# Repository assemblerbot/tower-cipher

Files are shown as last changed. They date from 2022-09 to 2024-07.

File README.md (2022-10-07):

# The Tower cipher
Mechanical 3D printable cipher device for **education and hobby purposes** only.
It's based on the similar principle as most rotor cipers.
The Tower cipher uses **5mm metalic (or glass) ball** as a signal carrier to trace letters through pseudo-random pathways inside rotors.

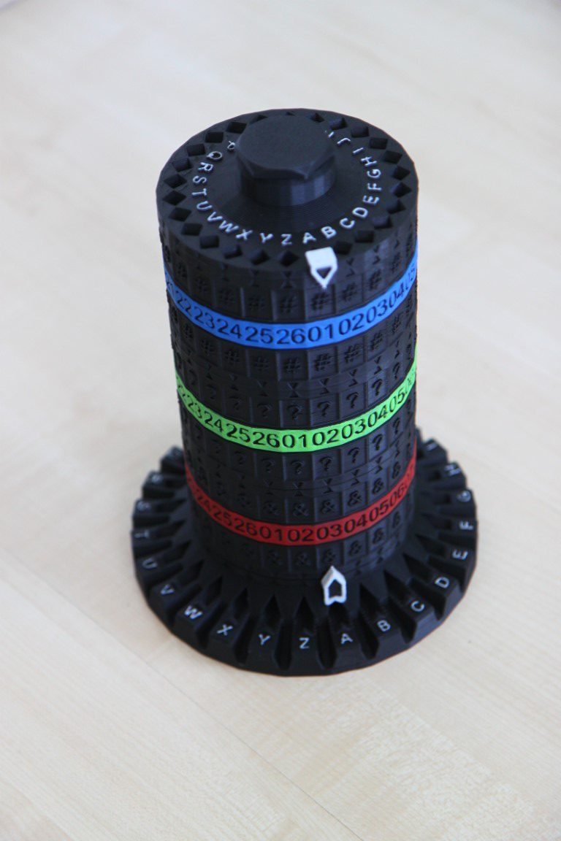
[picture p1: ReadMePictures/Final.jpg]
Final version


## Folders
[STL](https://github.com/assemblerbot/tower-cipher/tree/main/STL) contains printable files and assembly instructions.
In the [Model](https://github.com/assemblerbot/tower-cipher/tree/main/Model) folder there is a Blender source file for the whole device.
[Tools/Pathways generator](https://github.com/assemblerbot/tower-cipher/tree/main/Tools/PathwaysGenerator) is the tool I've created for generating internal pathways.

## Operation
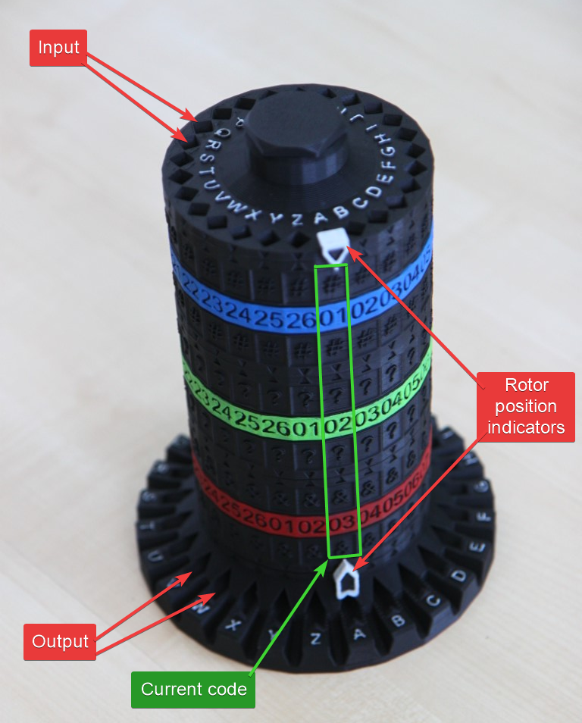
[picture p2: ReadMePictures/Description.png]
Description


### Video
[YouTube - how to use Tower cipher](https://youtu.be/TXNiqYJ8YBw)

### Printable sites
[Tower cipher on Printables](https://www.printables.com/model/290571-tower-cipher)

### Key
Secret phrase or the key consists of 2 mandatory parts and one optional part:
- order of rotors
- rotor settings
- optional - rotation pattern

Consider following example of the key (also on the picture above):
```
#01 ?02+1 &03
```

In this case:
- order of rotors from top to bottom in case of encryption and from bottom to top in case of decryption is `#?&`
- rotor `#` must be set to position `01`
- rotor `?` must be set to position `02`
- rotor `&` must be set to position `03`

There is also an optional rotation pattern: after each letter the position on the rotor `?` should be increased by `+1`.

### Encryption
1. Setup the device. Order of rotors is by the key **from top to bottom**.
2. Throw the ball to the letter hole on the top for next letter of a plaintext.
3. Ball returnes from one of bottom holes and indicates the letter from ciphertext.
4. Turn rotors by rotation pattern.
5. Repeat from step 2.

### Decryption
1. Setup the device. Order of rotors is inverted **from bottom to top**.
2. Throw the ball to the letter hole on the top for each ciphertext.
3. Ball returnes from one of bottom holes and indicates the letter from plaintext.
4. Turn rotors by rotation pattern.
5. Repeat from step 2.

## Additional features
There is a small ball storage on the top.
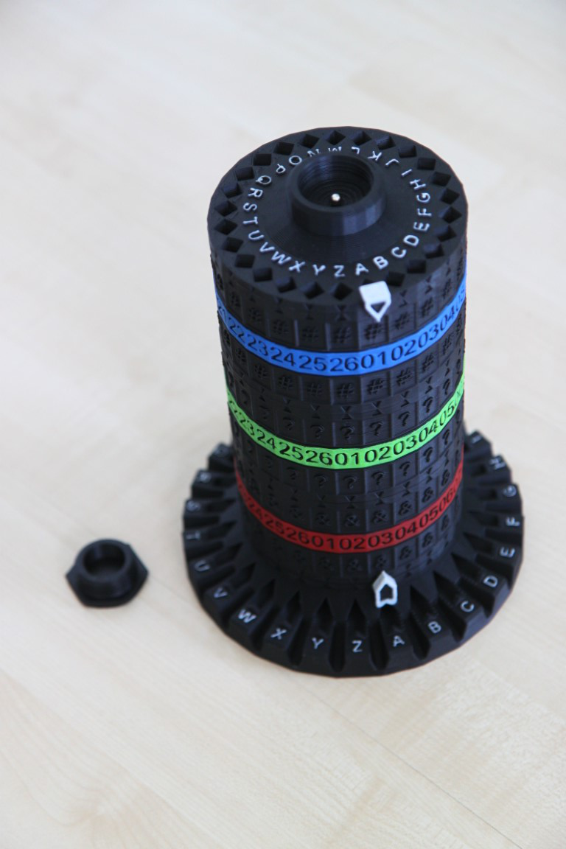
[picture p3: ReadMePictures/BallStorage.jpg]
Ball storage


Tweezers can be stored in a storage are at the bottom of the base part.
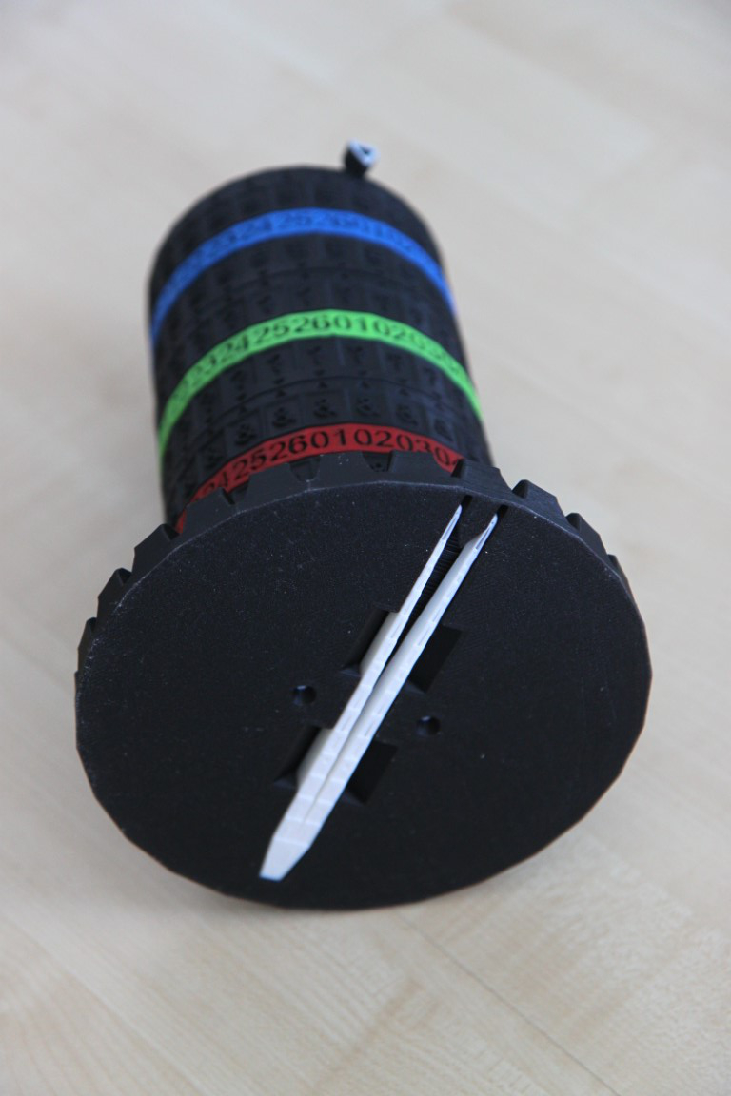
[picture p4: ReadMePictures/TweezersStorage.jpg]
Tweezers storage


## Notes

### Rotation pattern
Rotation pattern is optional.
If it's missing the device works as simple substitution cipher susceptible to frequency analysis.

### Internal rotor structure
Published version of Tower cipher uses 3 layers per each rotor where pin connections occur (see the Pathways generator for details).
Therefore randomness of connections is limited and is not entirely random.

Also straight connections (A to A) and short connections between neighbouring pins are not implemented.

### Key strength
Since the internal structure of the device is known, there are `3*2*1` combinations of rotor placements and `26*26*26` combinations of rotor positions which yields `105456` combinations the key without rotation patterns.
Rotation pattern can significantly increase the encryption strength yet too complex patterns might be hard to use.

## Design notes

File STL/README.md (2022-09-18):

# Tower cipher printing

## Prerequisites
You will need:
- 1 kg of filament (a bit less, but it depends on your slicer settings)
- 5mm metal or glass ball

## Slicing
I recommend following settings for Prusa slicer but of course you know your printer and what works for it the best.
Standard PLA, nozzle diameter 0.6mm, layer height 0.35, no supports are needed.

### Axle
This part should be strong.
- 3 perimeters
- 15% gyroid infill
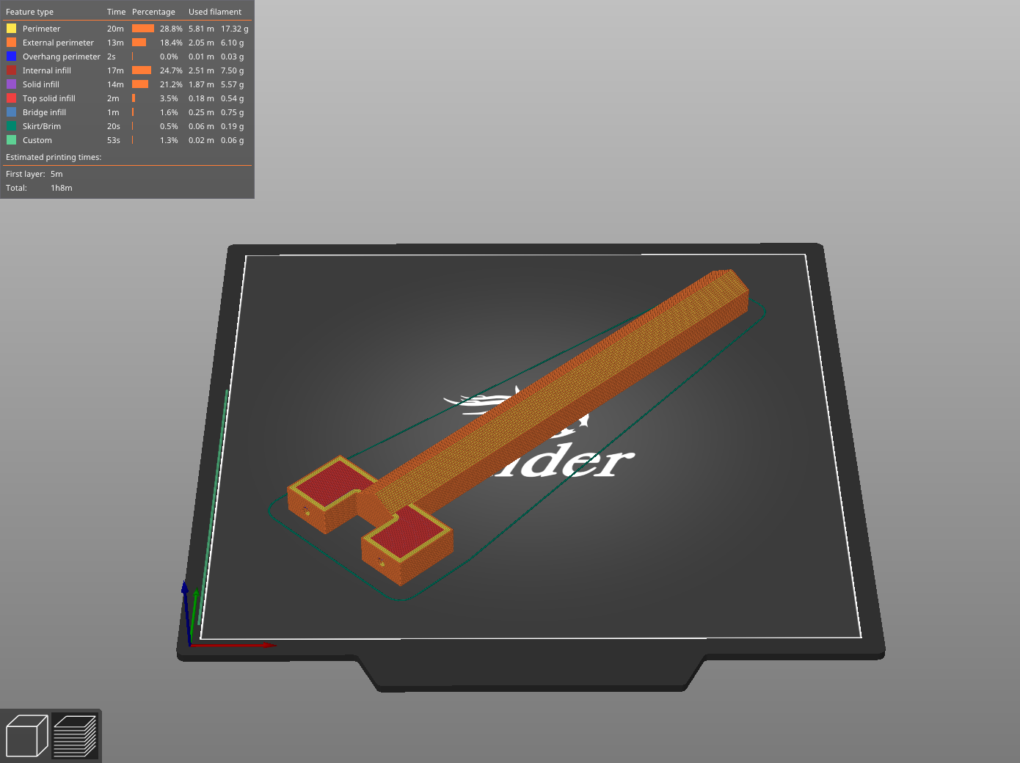
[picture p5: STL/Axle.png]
Axle


### Base, Top and Bolt
Nothing special, I've used:
- 2 perimeters
- 10% infill
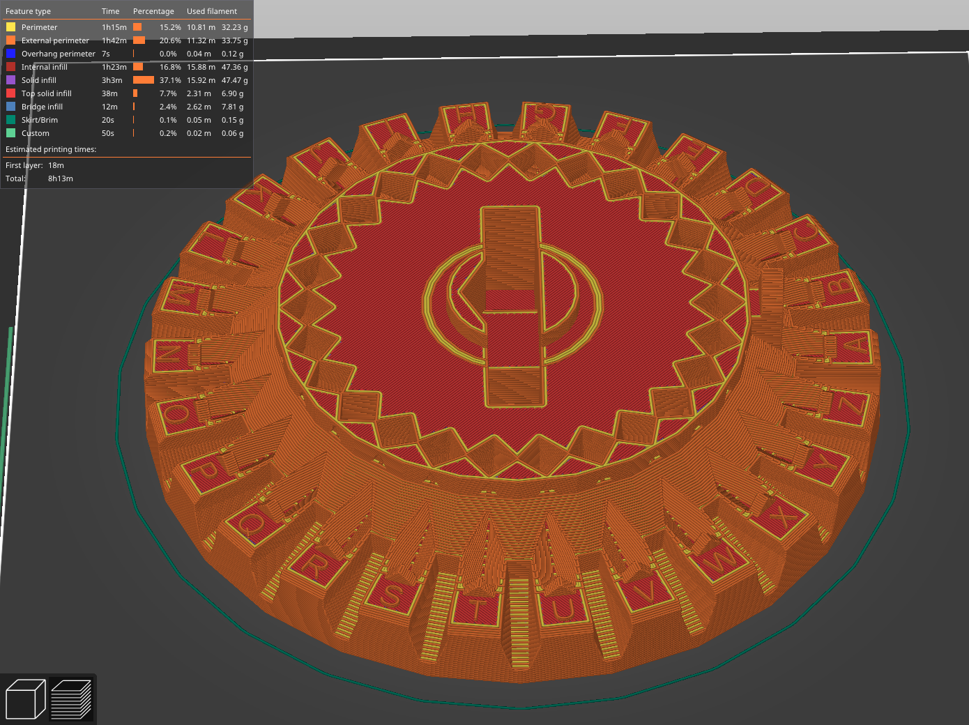
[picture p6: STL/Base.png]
Base


### Break
**Print it 3x** and with following parameters:
- 2 perimeters
- 15% infill
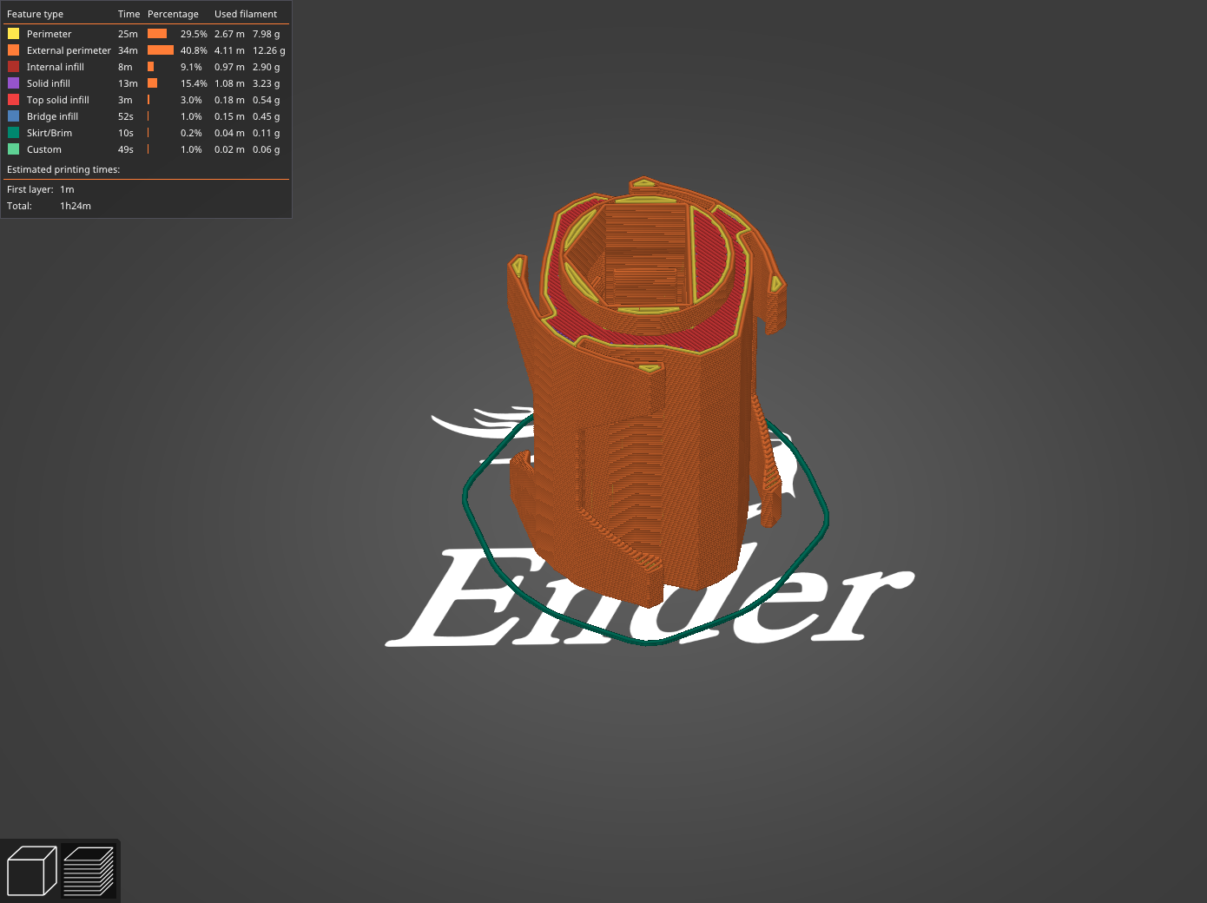
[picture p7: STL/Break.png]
Break


### Rotors
The tricky part. Can be printed on Enter 3 with default speeds under 10 hours with following settings:
- 2 perimeters
- **10% rectilinear infill**
- add range modifier between heights 1mm - 57mm and set *Bottom solid layers* and *Top solid layers* to 0
  - this setting significantly reduce printing time while that infill supports pathways nicely
- Solid infill threshold area: 0
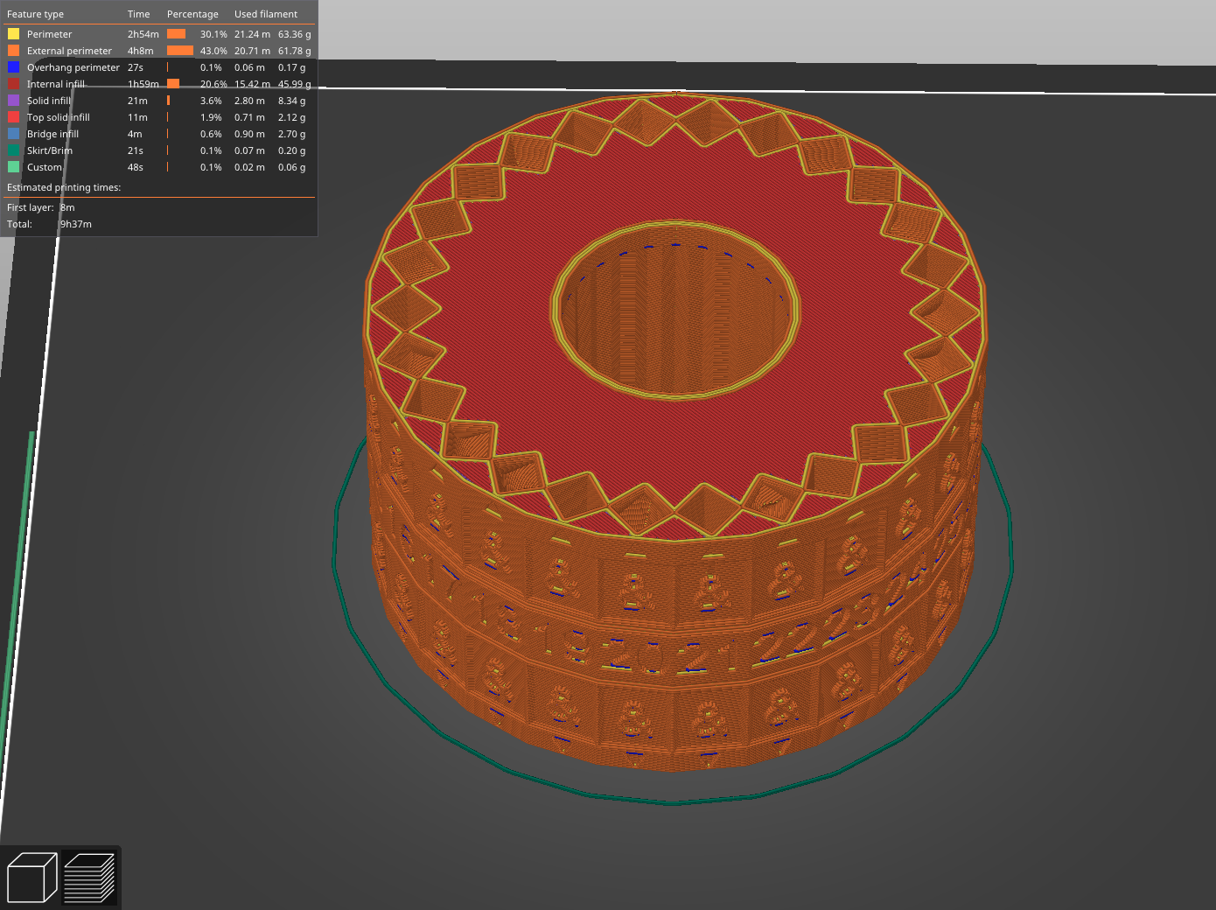
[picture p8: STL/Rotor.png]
Rotor


There is no need for solid infill inside the rotor.
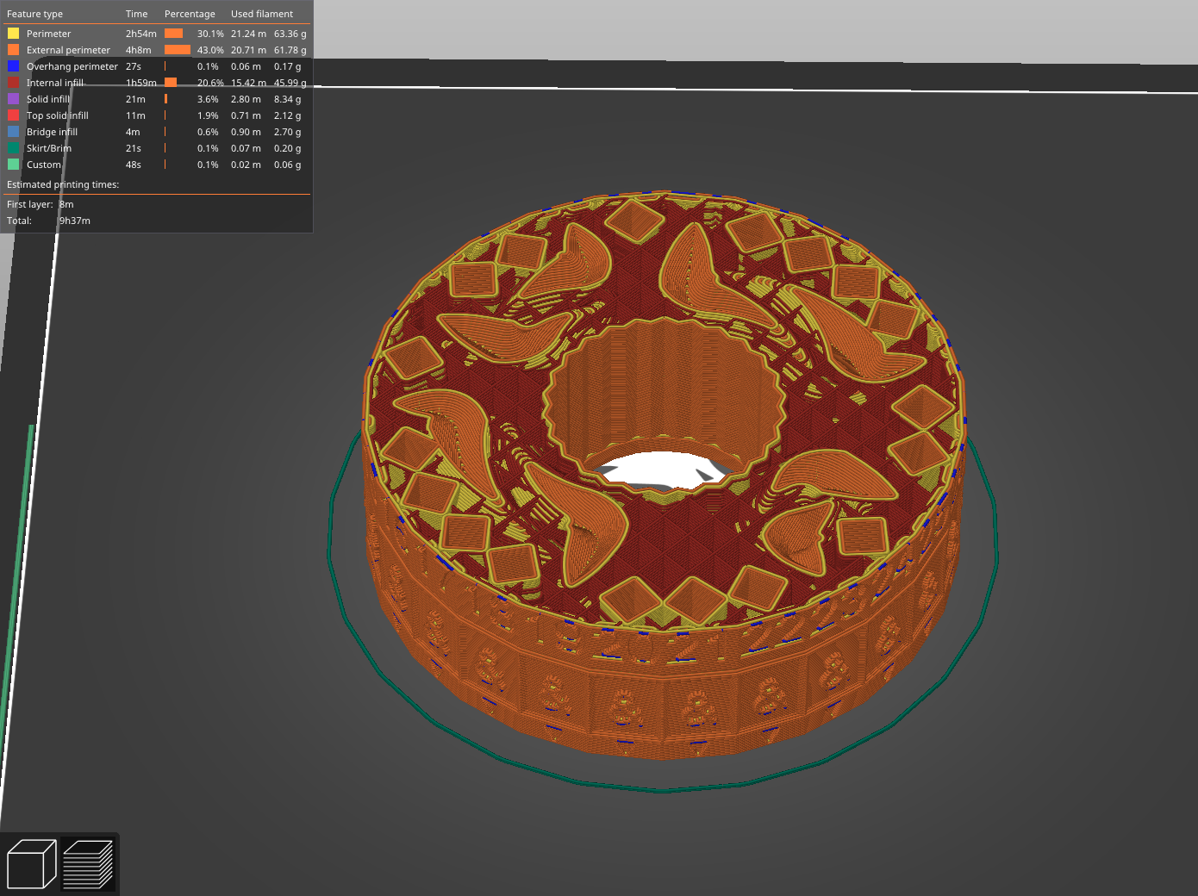
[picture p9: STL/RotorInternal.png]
RotorInternalStructure


### Tweezers
Tweezers can be a bit problematic if you have warping issues.
- 4 perimeters
- 15% infill (almost doesn't matter)
- I've turned off "Fill gaps" - that helped with warping because extruder is not returning back to fill in those tiny holes
- Classic perimeter generator instead of Arachne

## Printing
When your print is done you should have these parts.
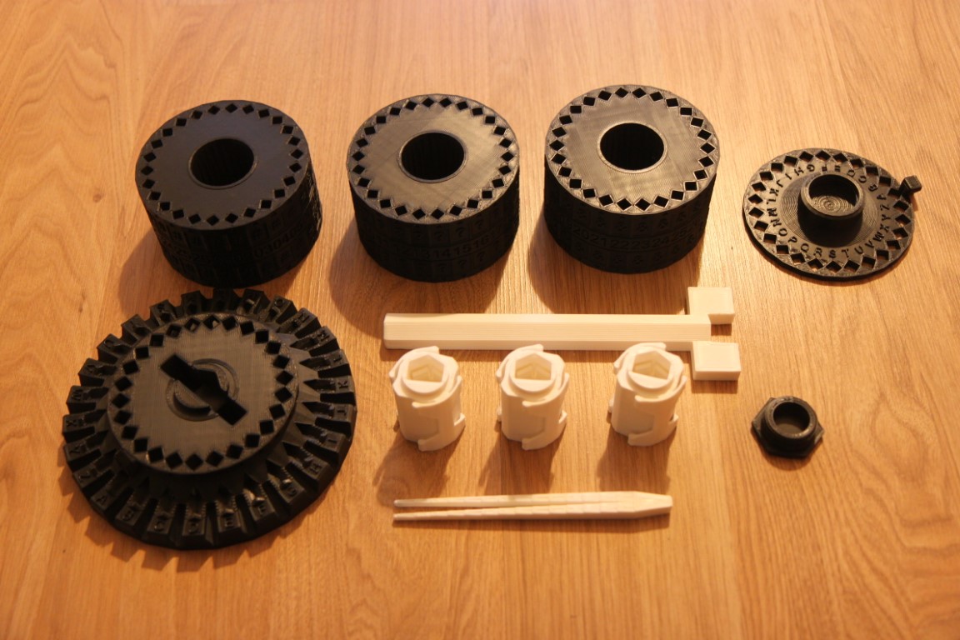
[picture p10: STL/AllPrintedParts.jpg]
All printed parts


## Assembly
Insert Axle into Base part (should be tight fit without any gabs, you can use a glue or any screws that fits the holes on the bottom if needed).

Insert Breaks into Rotors (see the picture).
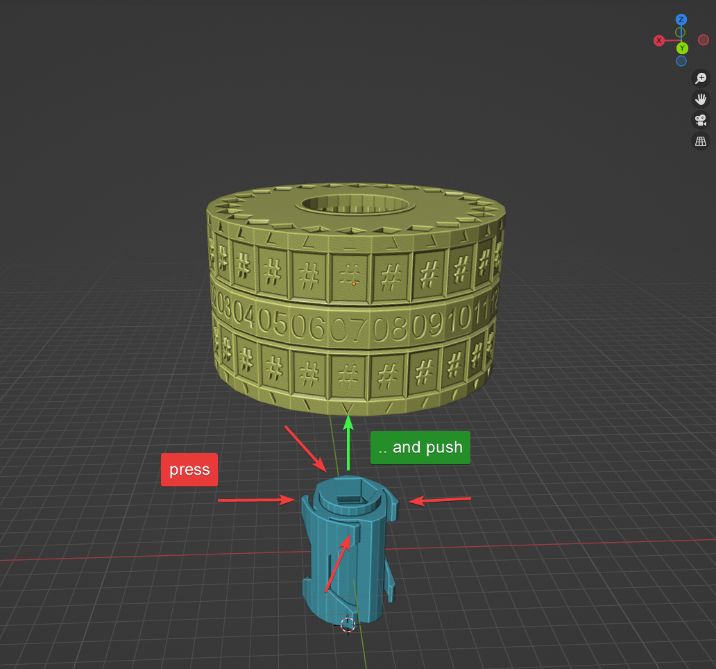
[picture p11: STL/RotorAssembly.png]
Rotor assembly


Assembled parts:
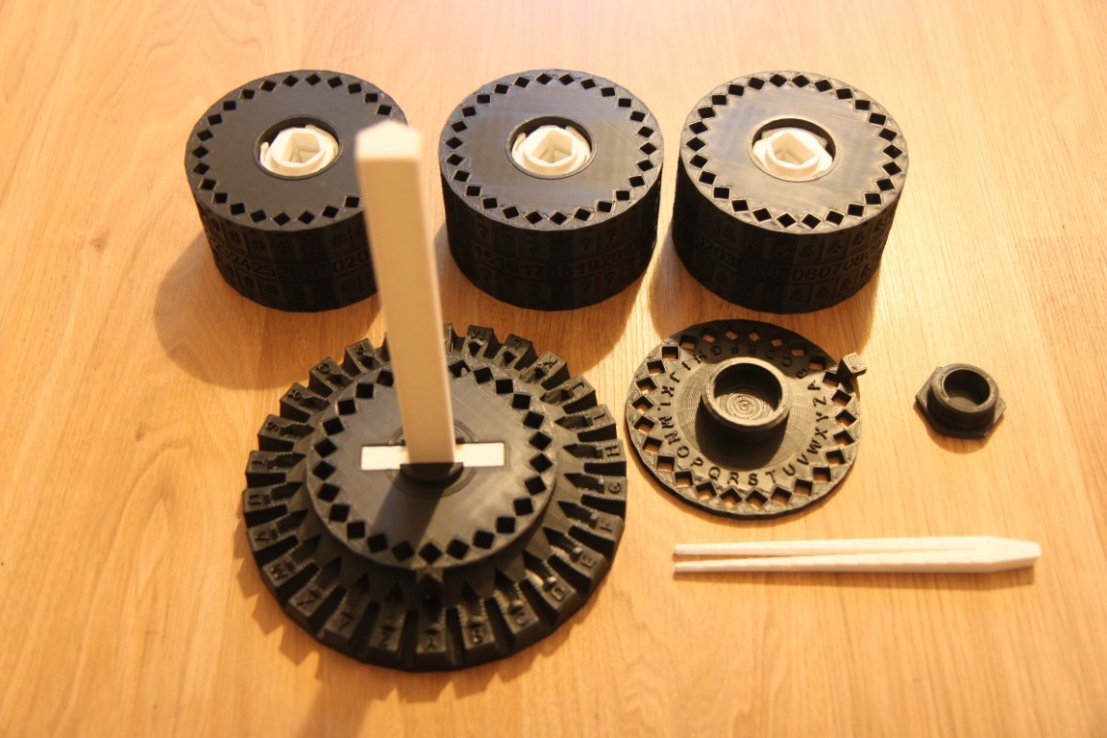
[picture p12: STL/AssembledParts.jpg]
Assembled parts


## Coloring
Optional, I've used Citadel acrylic paints for miniatures with black undercoat to increase readability of the letters and numbers.
Painted version

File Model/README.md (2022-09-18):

# Tower cipher mesh

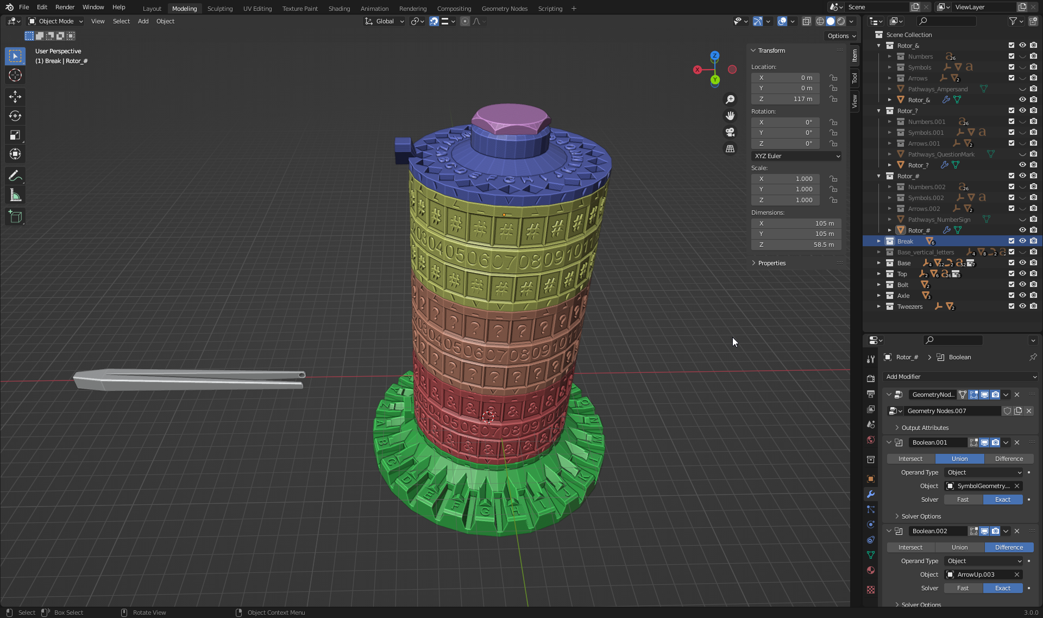
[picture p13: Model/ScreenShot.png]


I've tried to keep everything in Tower cipher model as parametric as possible.
Creating rotor should be fairly simple:
- create new pathways in Pathways generator tool
- import them into Blender
- align to existing pathways in one of the existing rotors
- change Symbol text on rotor (it's parametric, so it's really just one letter and it's done)
- export to STL
- import to slicer and **carefully check all layers if there are any glitches, holes, etc..**

### Note:
Most tolerances are made by Solidify modifier on "Hole" version of object.

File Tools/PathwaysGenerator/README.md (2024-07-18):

# Pathway generator
Pathway generator is a simple one purpose Unity project that I've used to generate internal pathways of the Tower cipher.
It's main purpose is to create mesh that represents internal structure - pathways - of Tower cipher rotors by following principle:
- there are "pins" around the rotor (now 26, but can be changed in definition)
- to avoid flipping the rotors in decryption process, connections between pins are organised as symmetric exchanges: if a pin A is connected with a pin B then the B is connected with the A
- exchanges are organized to layers
- each layer represents the one height where exchanges are created, each exchange consists of 2 connections: one runs on outer radius and one on the inner
- pathways are collision free
- pathways are 3D printable friendly (no bridges, no overhangs or other potentially problematic structures)

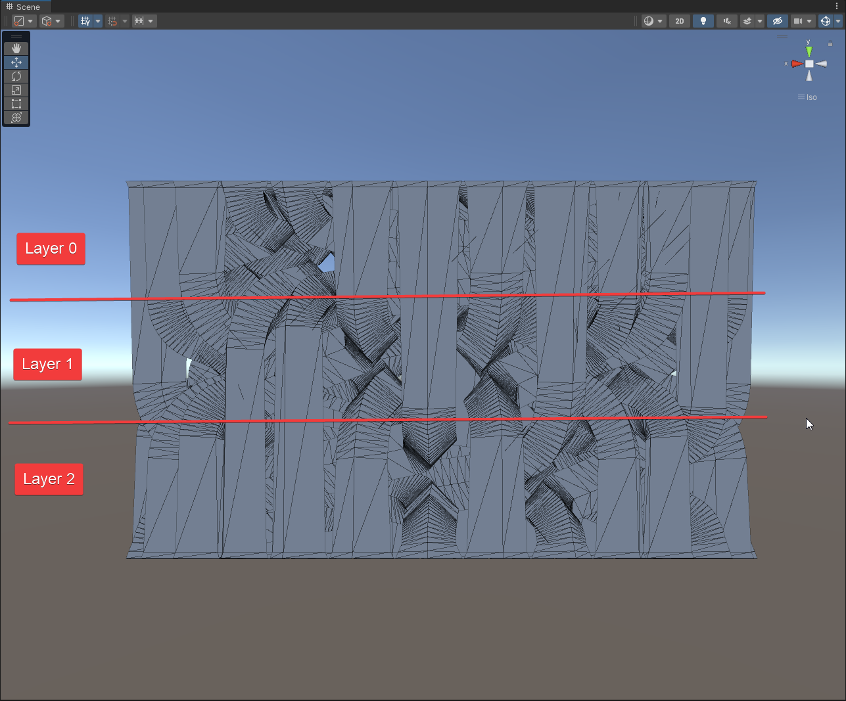
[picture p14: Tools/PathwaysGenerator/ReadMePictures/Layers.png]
Layers


Following conditions must be met in order to create good mesh:
- if there is a connection from pin A to pin B in layer N, there must be also connection from pin B to pin A in the same layer defined in "Connections" parameter
- minimal distance between connected pin A and B is 2 (shorter distances needs special handling and that's not implemented)
- layers the connections are in must correspond to Layers count in RotorDefinition

## Program functions
Open the MainScene and check the following picture.
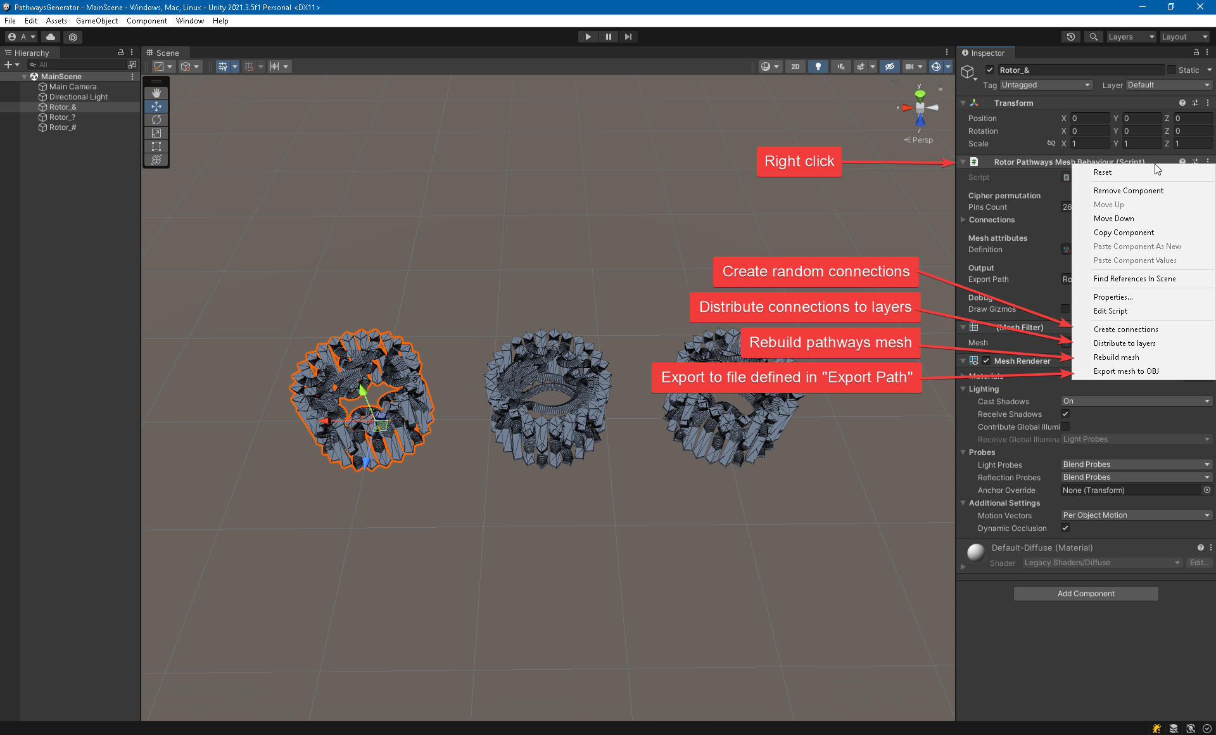
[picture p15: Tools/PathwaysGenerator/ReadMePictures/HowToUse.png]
Pathway generator usage


1. Create connections - fill connections with random values. *This is just experimental feature, it will generate random connections but they will probably not fit into given layers!*

2. Distribute to layers - first fit search also *highly experimental*.

3. Rebuild mesh - create mesh from given connections.

4. Export mesh to OBJ - export mesh to a file defined by **Export Path** parameter.

## Real usage
If you want to really create new pathways in current 3 layer setup then use following procedure:
- take pen and paper (I'm not joking)
- draw a large circle
- create 26 marks around it and write also they numeric values
- create connections by following rules:
  - distance between two connected pins must be at least 2 (generator doesn't work well on neighbouring numbers)
  - connections must not overlap in the same layer
  - connect all pins
- fill connections manually (forward and backward - from A to B and B to A should in the same layer)
- run Rebuild mesh
- run Export mesh to OBJ if everything looks good
- import to Blender
- snap to position of previous pathways in the rotor you've chosen
- replace pathways mesh in boolean operation of the rotor
- export rotor to STL
- import to slicer
- **carefully check sliced rotor layer by layer if there are any glitches, pathways overlaps, holes and so on**
- print

Rotors I've created look like this:
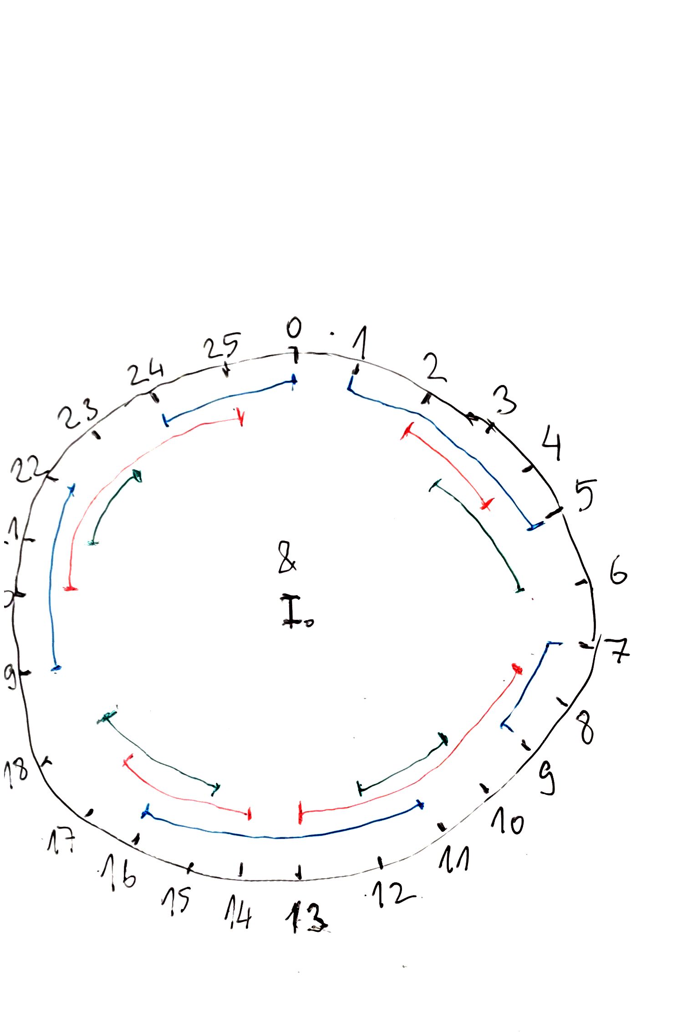
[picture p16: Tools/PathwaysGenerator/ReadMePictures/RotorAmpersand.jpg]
Rotor &

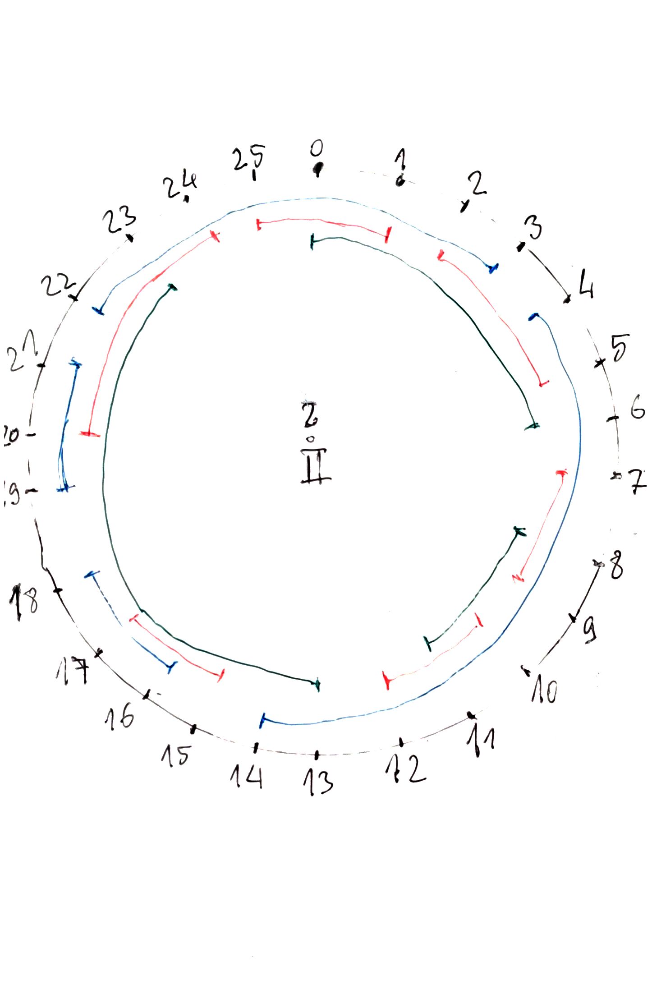
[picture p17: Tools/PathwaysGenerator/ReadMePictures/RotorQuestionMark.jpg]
Rotor ?

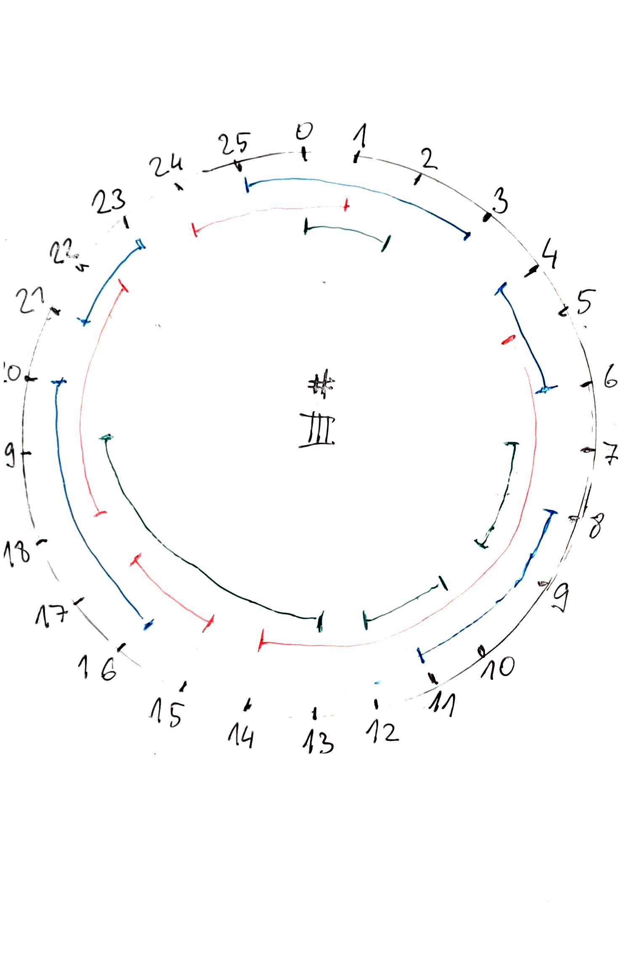
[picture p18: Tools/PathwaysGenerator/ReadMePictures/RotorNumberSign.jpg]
Rotor #


### Note:
Steepness of a pathway decreases with the distance between connected pins. From my experience pathways that are close to 13 pins long may cause the ball stop inside the rotor. 

## Notes
Whole code is written for single purpose, it works as it is but **edge-cases are not covered**. Use it at your own risk.

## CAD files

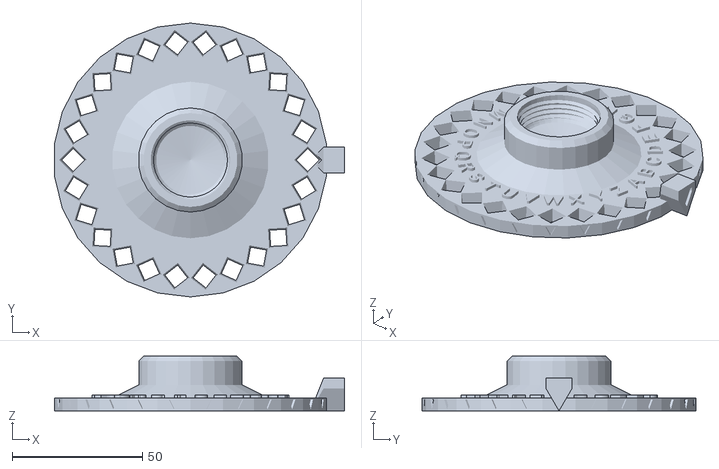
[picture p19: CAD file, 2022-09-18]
STL/Top.stl
111.2 x 105.0 x 21.0

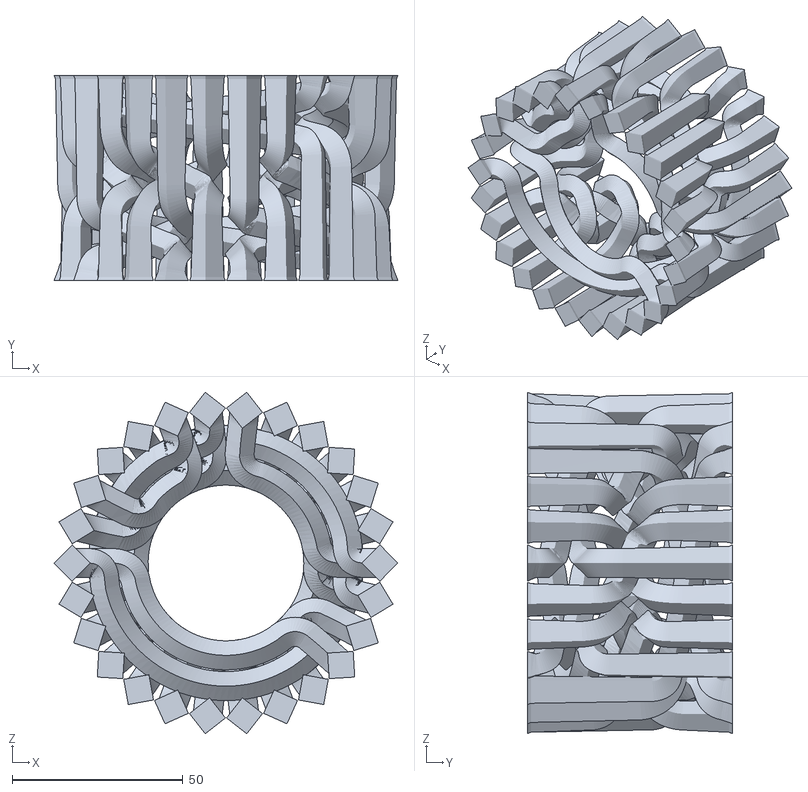
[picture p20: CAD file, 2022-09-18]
Tools/PathwaysGenerator/Pathways_QuestionMark.obj
100.6 x 60.0 x 99.9

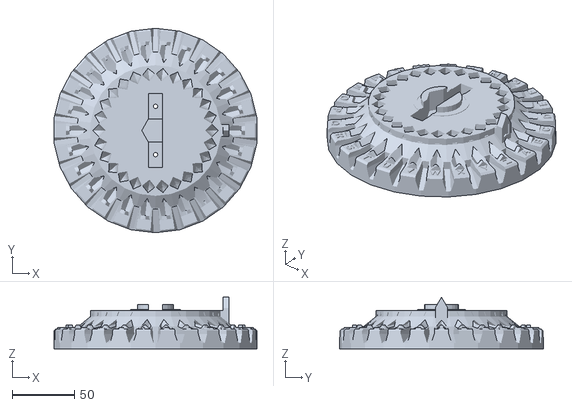
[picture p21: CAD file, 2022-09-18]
STL/Base.stl
163.0 x 164.2 x 41.6

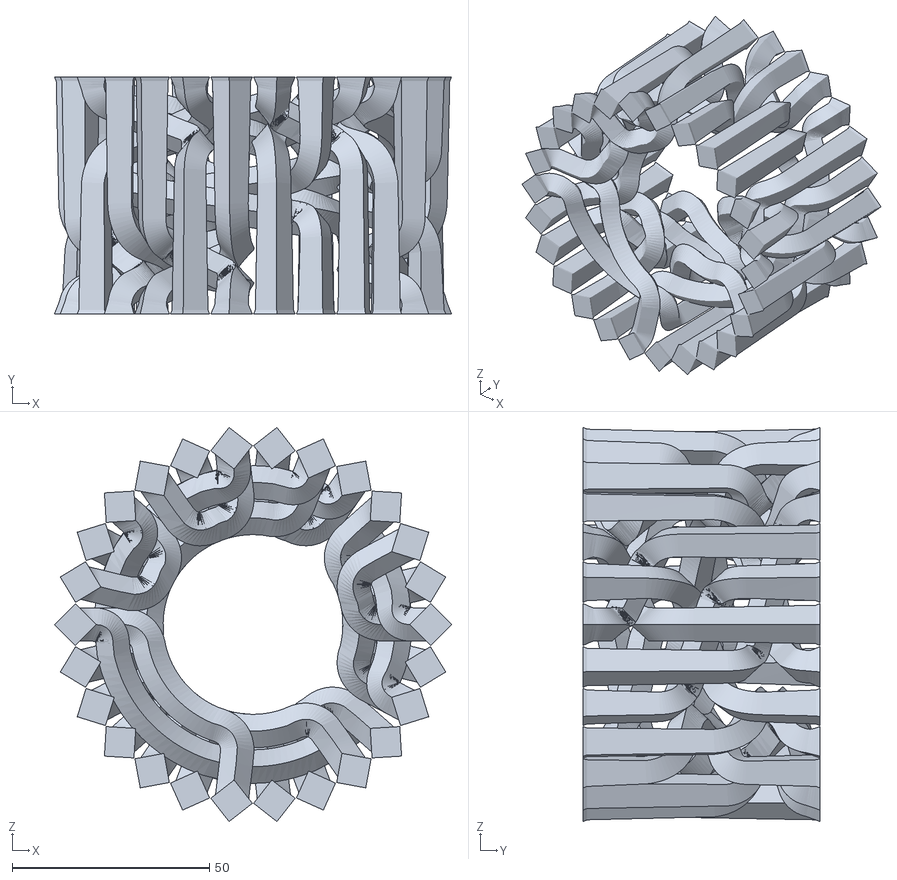
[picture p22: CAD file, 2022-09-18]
Tools/PathwaysGenerator/Pathways_NumberSign.obj
100.6 x 60.0 x 99.9

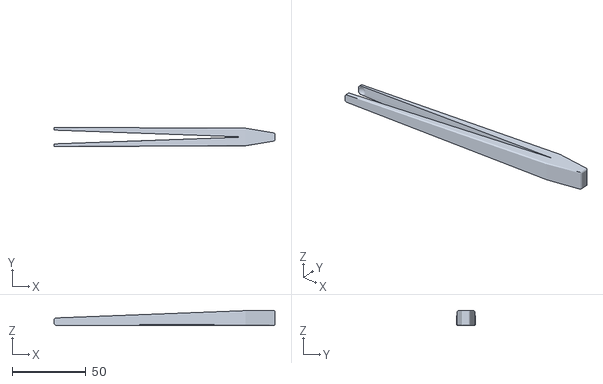
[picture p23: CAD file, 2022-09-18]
STL/Tweezers.stl
150.0 x 13.0 x 10.0

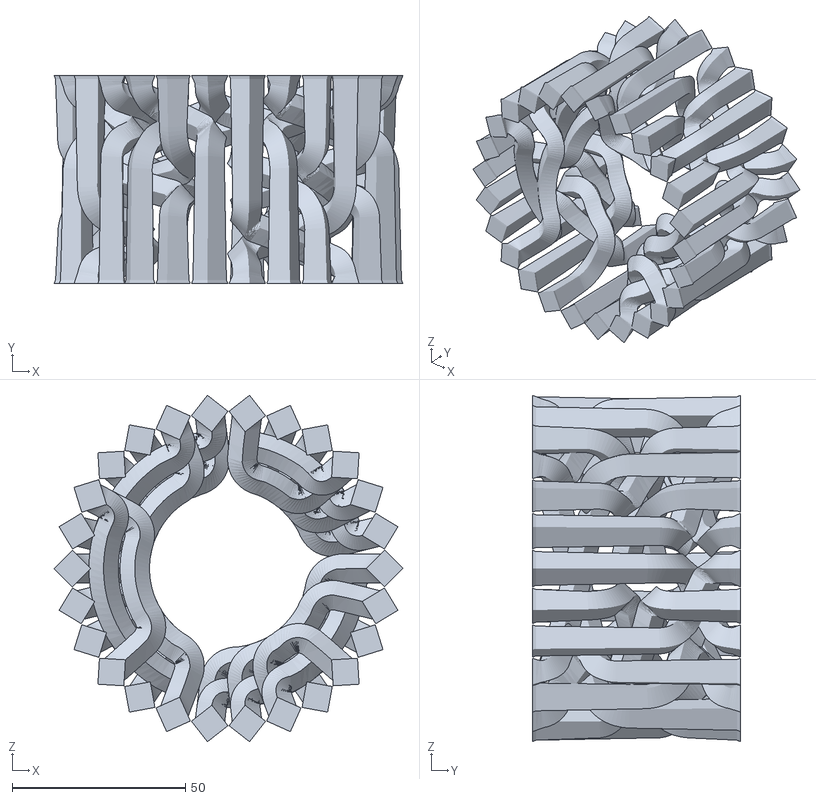
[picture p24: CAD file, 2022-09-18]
Tools/PathwaysGenerator/Pathways_Ampersand.obj
100.6 x 60.0 x 99.9

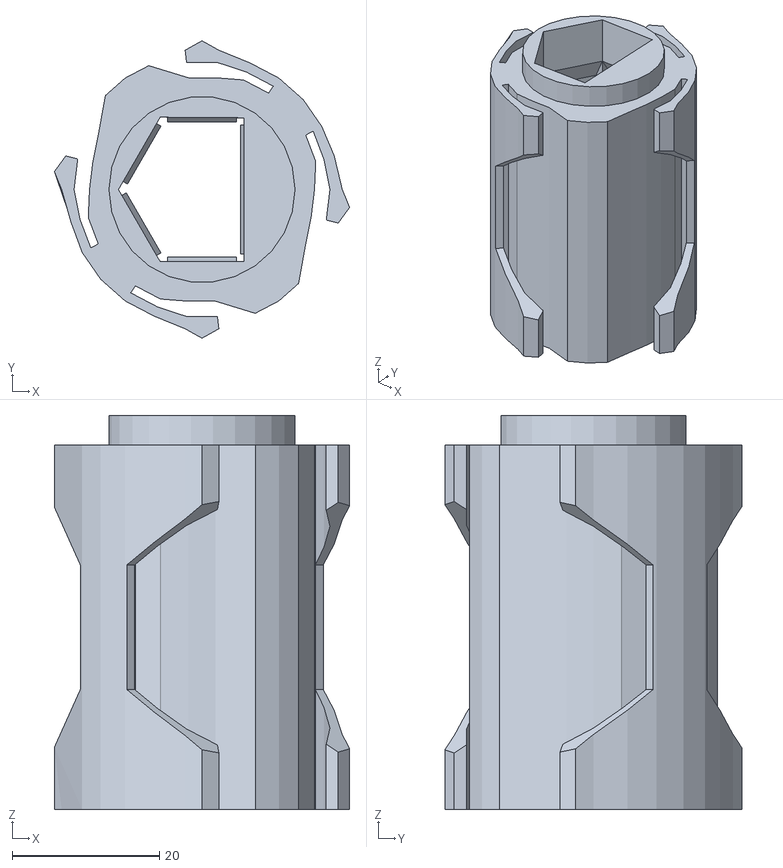
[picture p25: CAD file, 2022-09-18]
STL/Break.stl
40.1 x 40.4 x 53.5

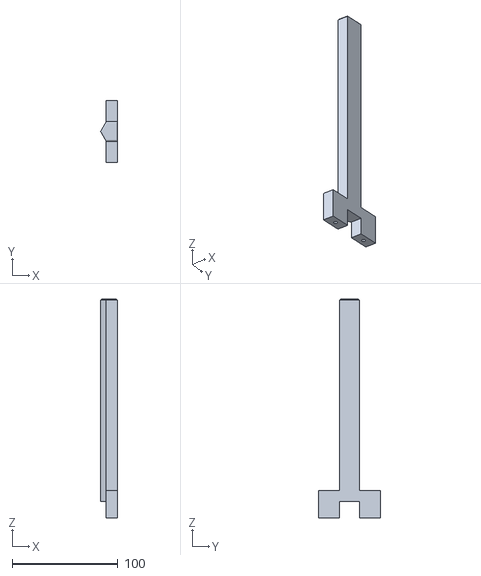
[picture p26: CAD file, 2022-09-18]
STL/Axle.stl
16.0 x 58.8 x 207.0

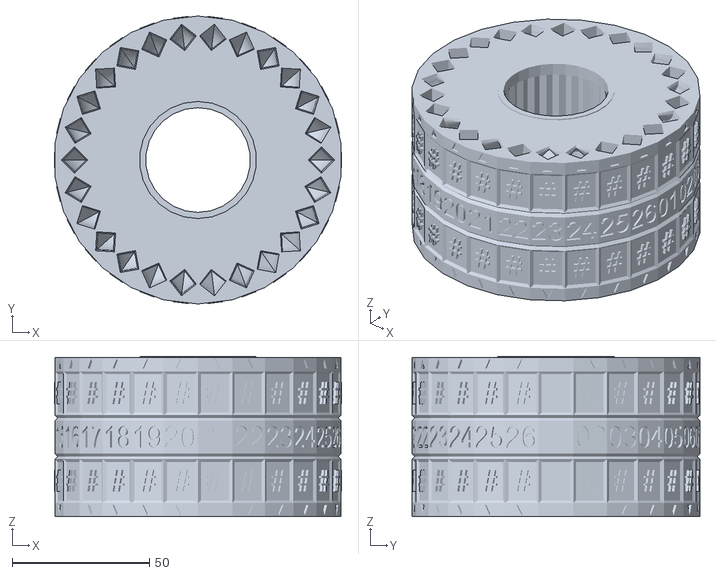
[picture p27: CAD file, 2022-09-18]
STL/Rotor_NumberSign.stl
104.8 x 105.0 x 58.5

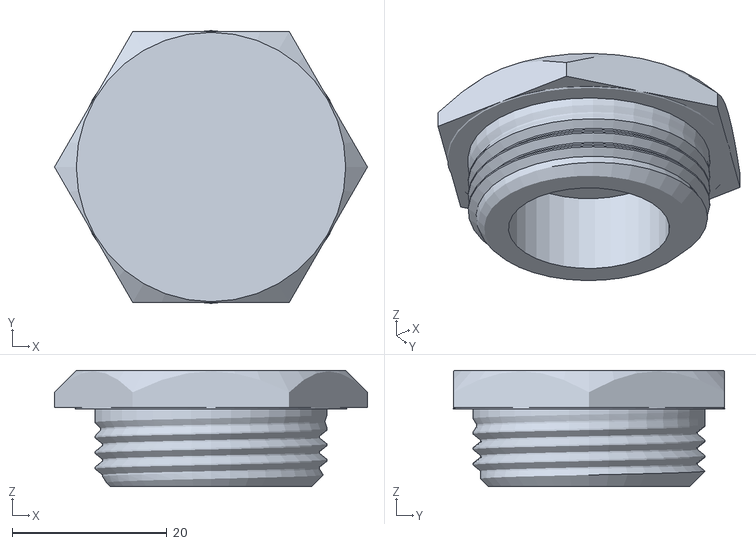
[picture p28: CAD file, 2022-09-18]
STL/Bolt.stl
40.4 x 35.2 x 15.0

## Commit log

2022-09-18 [Update] Initial content commit.
    [Pathways_Ampersand.obj, Pathways_NumberSign.obj, Pathways_QuestionMark.obj]
2022-09-18 [Update] README
    [Axle.stl, Base.stl, Bolt.stl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]
2022-09-18 [Update] STL readme.
2022-10-07 [Update] Added Printables link to readme.
